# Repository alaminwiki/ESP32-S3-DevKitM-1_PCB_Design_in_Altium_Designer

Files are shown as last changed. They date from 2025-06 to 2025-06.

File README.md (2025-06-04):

Project Highlights:

Designed a 4-layer PCB stack-up to enhance signal integrity and power distribution

Created and customized schematic symbols

Sourced many footprints and 3D model from SnapMagic and Ultra Librarian and also modified some footprint

Explored Differential Pair Routing For high-speed  signals

Used a TVS (Transient Voltage Suppression) diode to protect the microcontroller, USB interface, and power lines from sudden voltage spikes caused by ESD events.

Implemented strategic component placement and return path optimization to mitigate EMI issues, carefully planned layout and return paths to reduce noise, and enhanced board-level EMC performance to meet industry standards 

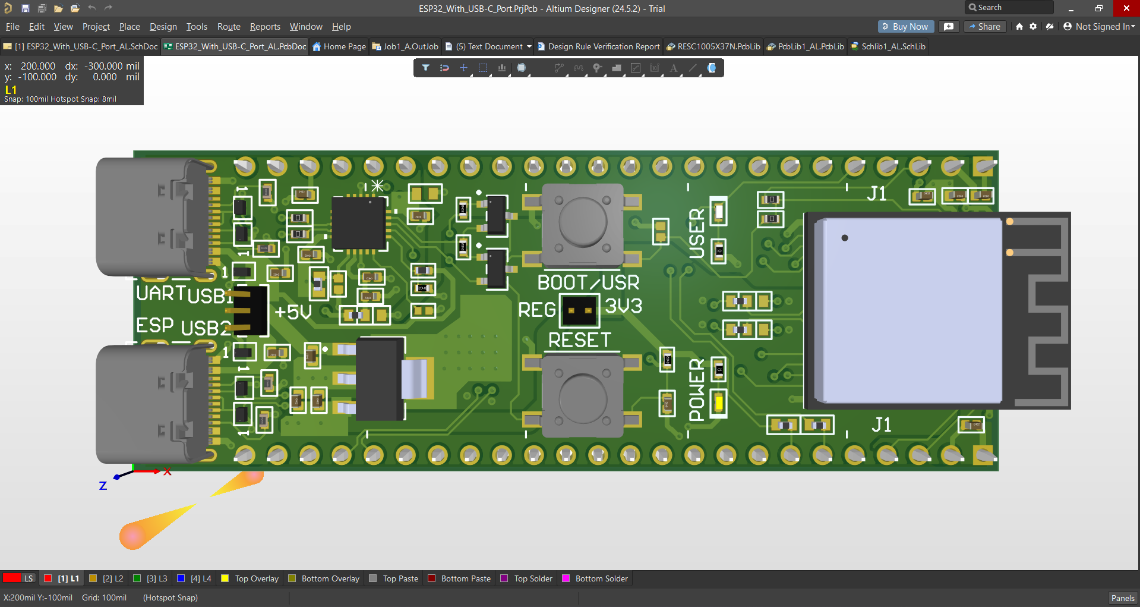
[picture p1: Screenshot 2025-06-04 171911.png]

![image alt]()

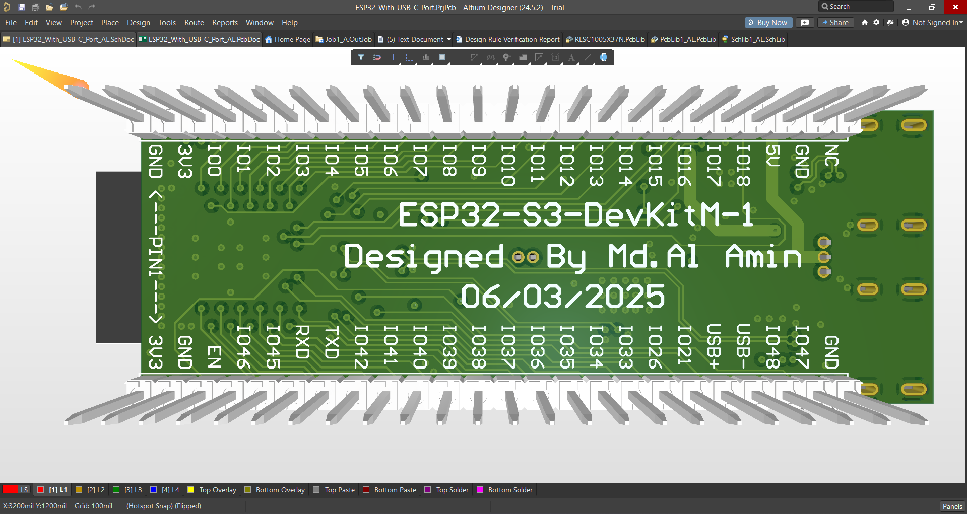
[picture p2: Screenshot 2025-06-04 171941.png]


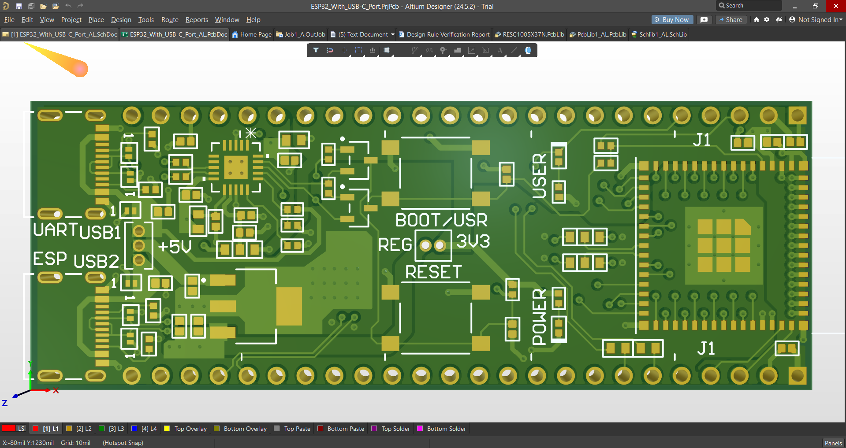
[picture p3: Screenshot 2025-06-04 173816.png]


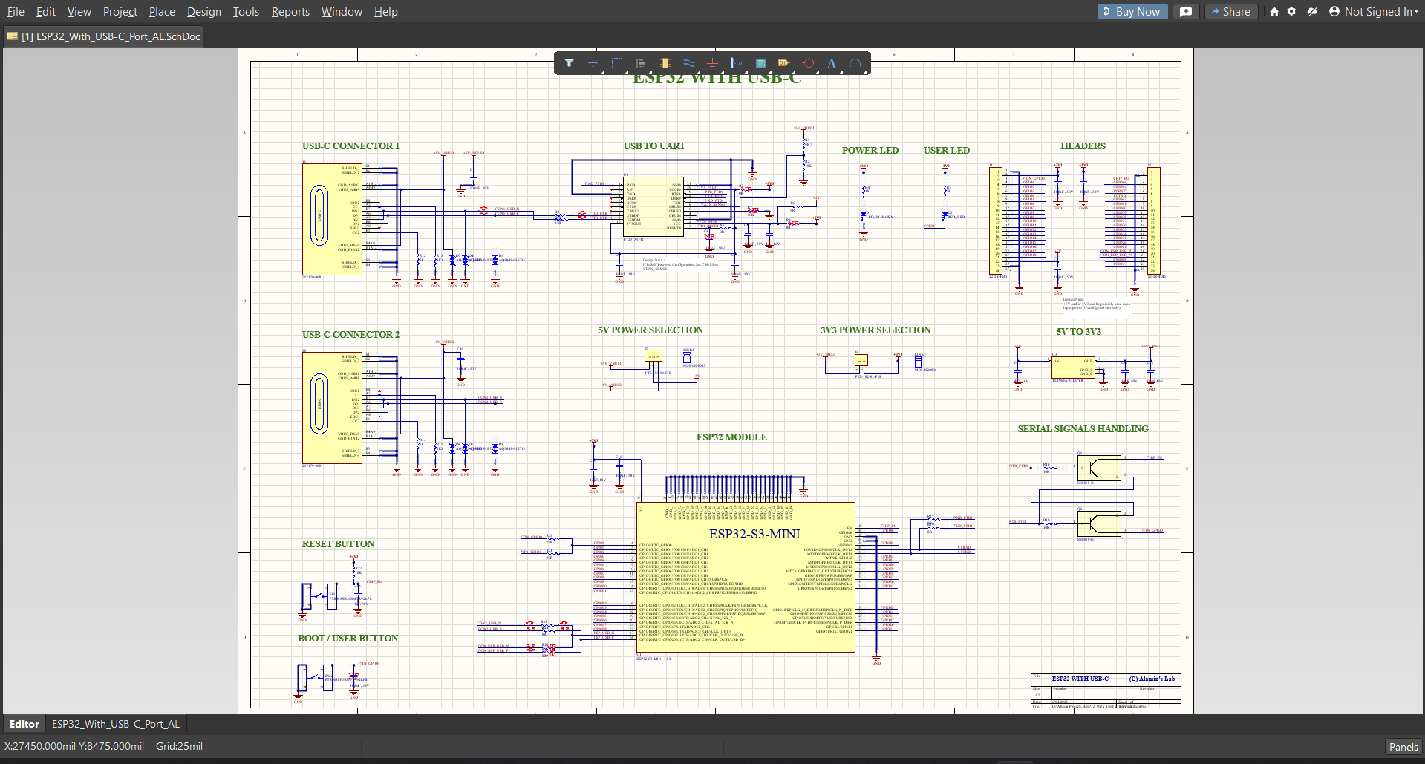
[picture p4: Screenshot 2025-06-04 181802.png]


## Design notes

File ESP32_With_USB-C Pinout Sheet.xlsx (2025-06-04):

1 | GND_1
2 | GND_2
3 | 3V3
4 | GPIO0/RTC_GPIO0
5 | GPIO1/RTC_GPIO1/TOUCH1/ADC1_CH0
6 | GPIO2/RTC_GPIO2/TOUCH2/ADC1_CH1
7 | GPIO3/RTC_GPIO3/TOUCH3/ADC1_CH2
8 | GPIO4/RTC_GPIO4/TOUCH4/ADC1_CH3
9 | GPIO5/RTC_GPIO5/TOUCH5/ADC1_CH4
10 | GPIO6/RTC_GPIO6/TOUCH6/ADC1_CH5
11 | GPIO7/RTC_GPIO7/TOUCH7/ADC1_CH6
12 | GPIO8/RTC_GPIO8/TOUCH8/ADC1_CH7/SUBSPICS1
13 | GPIO9/RTC_GPIO9/TOUCH9/ADC1_CH8/FSPIHD/SUBSPIHD
14 | GPIO10/RTC_GPIO10/TOUCH10/ADC1_CH9/FSPICS0/FSPIIO4/SUBSPICS0
15 | GPIO11/RTC_GPIO11/TOUCH11/ADC2_CH0/FSPID/FSPIIO5/SUBSPID
16 | GPIO12/RTC_GPIO12/TOUCH12/ADC2_CH1/FSPICLK/FSPIIO6/SUBSPICLK
17 | GPIO13/RTC_GPIO13/TOUCH13/ADC2_CH2/FSPIQ/FSPIIO7/SUBSPIQ
18 | GPIO14/RTC_GPIO14/TOUCH14/ADC2_CH3/FSPIWP/FSPIDQS/SUBSPIWP
19 | GPIO15/RTC_GPIO15/U0RTS/ADC2_CH4/XTAL_32K_P
20 | GPIO16/RTC_GPIO16/U0CTS/ADC2_CH5/XTAL_32K_N
21 | GPIO17/RTC_GPIO17/U1TXD/ADC2_CH6
22 | GPIO18/RTC_GPIO18/U1RXD/ADC2_CH7/CLK_OUT3
23 | GPIO19/RTC_GPIO19/U1RTS/ADC2_CH8/CLK_OUT2/USB_D
24 | GPIO20/RTC_GPIO20/U1CTS/ADC2_CH9/CLK_OUT1/USB_D+
25 | GPIO21/RTC_GPIO21
26 | GPIO26/SPICS1
27 | GPIO47/SPICLK_P_DIFF/SUBSPICLK_P_DIFF
28 | GPIO33/SPIIO4/FSPIHD/SUBSPIHD
29 | GPIO34/SPIIO5/FSPICS0/SUBSPICS0
30 | GPIO48/SPICLK_N_DIFF/SUBSPICLK_N_DIFF
31 | GPIO35/SPIIO6/FSPID/SUBSPID
32 | GPIO36/SPIIO7/FSPICLK/SUBSPICLK
33 | GPIO37/SPIDQS/FSPIQ/SUBSPIQ
34 | GPIO38/FSPIWP/SUBSPIWP
35 | MTCK/GPIO39/CLK_OUT3/SUBSPICS1
36 | MTDO/GPIO40/CLK_OUT2
37 | MTDI/GPIO41/CLK_OUT1
38 | MTMS, GPIO42
39 | U0TXD, GPIO43, CLK_OUT1
40 | U0RXD, GPIO44, CLK_OUT2
41 | GPIO45
42 | GND
43 | GND
44 | GPIO46
45 | EN
46 | GND_46
47 | GND_47
48 | GND_48
49 | GND_49
50 | GND_50
51 | GND_51
52 | GND_52
53 | GND_53
54 | GND_54
55 | GND_55
56 | GND_56
57 | GND_57
58 | GND_58
59 | GND_59
60 | GND_60
61 | GND_61
62 | GND_62
63 | GND_63
64 | GND_64
65 | GND_65
66 | GND_66
67 | GND_67
68 | GND_68
69 | GND_69
70 | GND_70
71 | GND_71
72 | GND_72
73 | GND_73

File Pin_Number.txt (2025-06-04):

 RTC_GPIO1,GPIO1,TOUCH1,ADC1_CH0
 RTC_GPIO2,GPIO2,TOUCH2,ADC1_CH1
 RTC_GPIO3,GPIO3,TOUCH3,ADC1_CH2
 RTC_GPIO4,GPIO4,TOUCH4,ADC1_CH3
 RTC_GPIO5,GPIO5,TOUCH5,ADC1_CH4
 RTC_GPIO6,GPIO6,TOUCH6,ADC1_CH5
 RTC_GPIO7,GPIO7,TOUCH7,ADC1_CH6
 RTC_GPIO8,GPIO8,TOUCH8,ADC1_CH7,SUBSPICS1
 RTC_GPIO9,GPIO9,TOUCH9,ADC1_CH8,FSPIHD,SUBSPIHD
 RTC_GPIO10,GPIO10,TOUCH10,ADC1_CH9,FSPICS0,FSPIIO4,SUBSPICS0
 RTC_GPIO11,GPIO11,TOUCH11,ADC2_CH0,FSPID,FSPIIO5,SUBSPID
 RTC_GPIO12,GPIO12,TOUCH12,ADC2_CH1,FSPICLK,FSPIIO6,SUBSPICLK
 RTC_GPIO13,GPIO13,TOUCH13,ADC2_CH2,FSPIQ,FSPIIO7,SUBSPIQ
 RTC_GPIO14,GPIO14,TOUCH14,ADC2_CH3,FSPIWP,FSPIDQS,SUBSPIWP
 RTC_GPIO15,GPIO15,U0RTS,ADC2_CH4,XTAL_32K_P
 RTC_GPIO16,GPIO16,U0CTS,ADC2_CH5,XTAL_32K_N
 RTC_GPIO17,GPIO17,U1TXD,ADC2_CH6
 RTC_GPIO18,GPIO18,U1RXD,ADC2_CH7,CLK_OUT3
 RTC_GPIO19,GPIO19,U1RTS,ADC2_CH8,CLK_OUT2,USB_D
 RTC_GPIO20,GPIO20,U1CTS,ADC2_CH9,CLK_OUT1,USB_D+
 RTC_GPIO21,GPIO21
 SPICS1,GPIO26
 SPICLK_P_DIFF,GPIO47,SUBSPICLK_P_DIFF
 SPIIO4,GPIO33,FSPIHD,SUBSPIHD
 SPIIO5,GPIO34,FSPICS0,SUBSPICS0
 SPICLK_N_DIFF,GPIO48,SUBSPICLK_N_DIFF
 SPIIO6,GPIO35,FSPID,SUBSPID
 SPIIO7,GPIO36,FSPICLK,SUBSPICLK
 SPIDQS,GPIO37,FSPIQ,SUBSPIQ
 GPIO38,FSPIWP,SUBSPIWP
 MTCK,GPIO39,CLK_OUT3,SUBSPICS1
 MTDO,GPIO40,CLK_OUT2
 MTDI,GPIO41,CLK_OUT1

MTMS, GPIO42
U0TXD, GPIO43, CLK_OUT1
U0RXD, GPIO44, CLK_OUT2
GPIO45
GPIO46

EN 45 I
High: on, enables the chip.
Low: off, the chip powers off.
Note: Do not leave the EN pin floating.

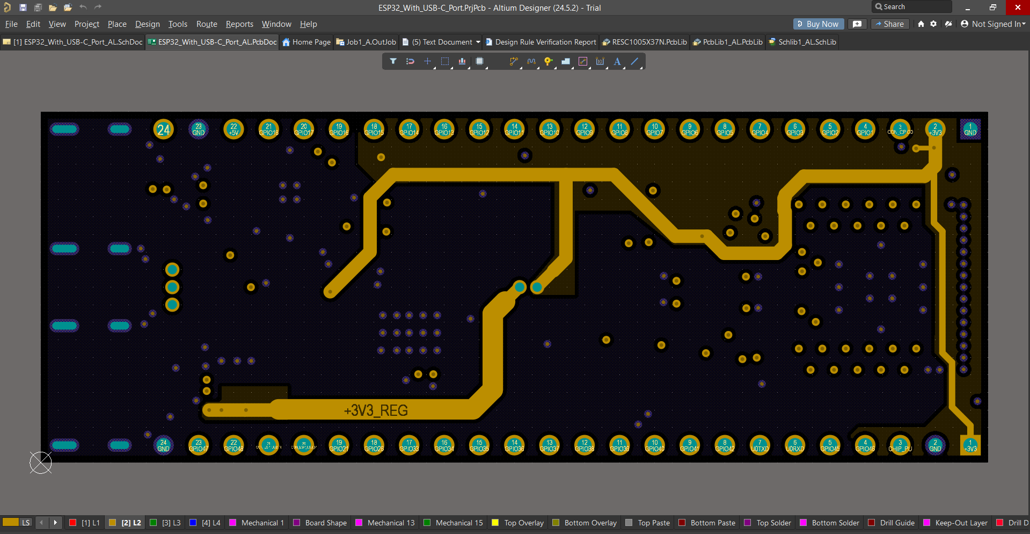
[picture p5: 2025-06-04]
Screenshot 2025-06-04 172349.png

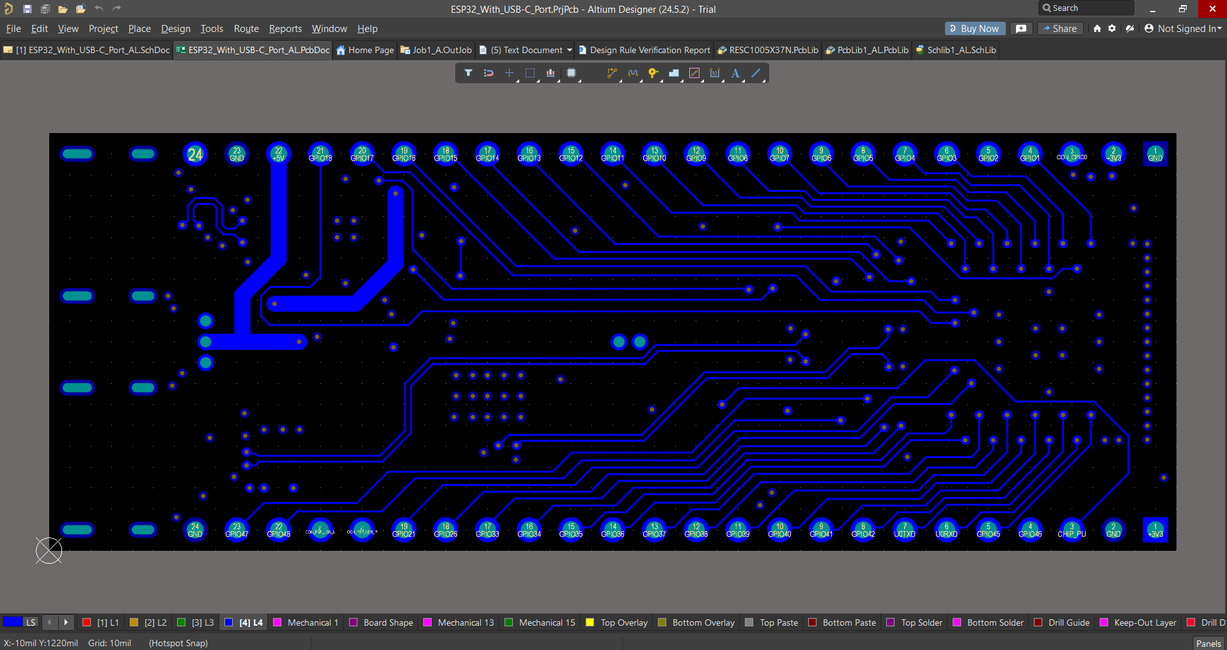
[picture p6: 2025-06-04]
Screenshot 2025-06-04 172502.png

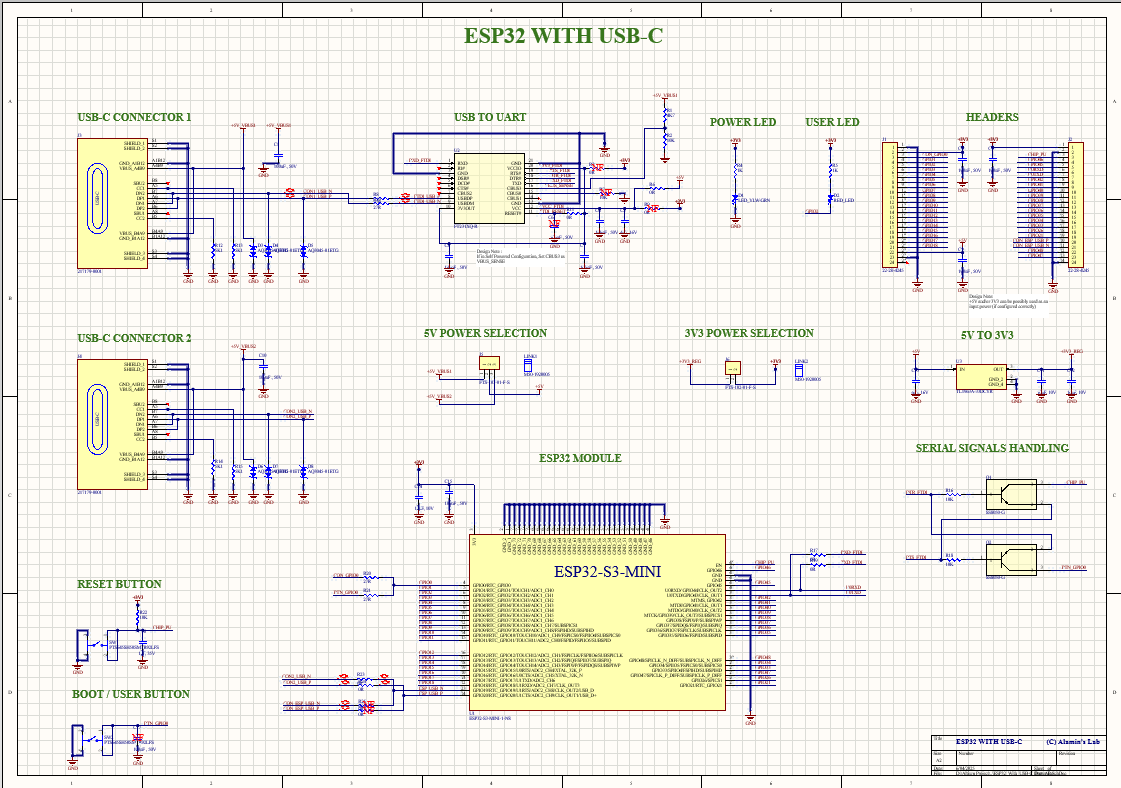
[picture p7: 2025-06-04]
Screenshot 2025-06-04 172717.png

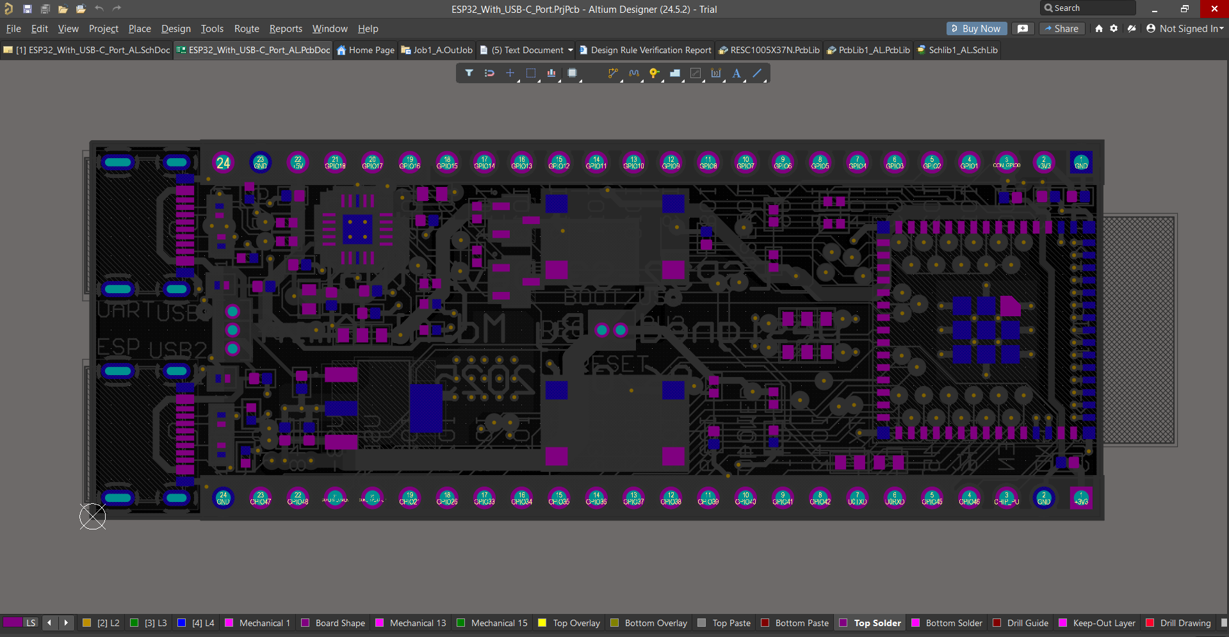
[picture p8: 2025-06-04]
Screenshot 2025-06-04 180557.png

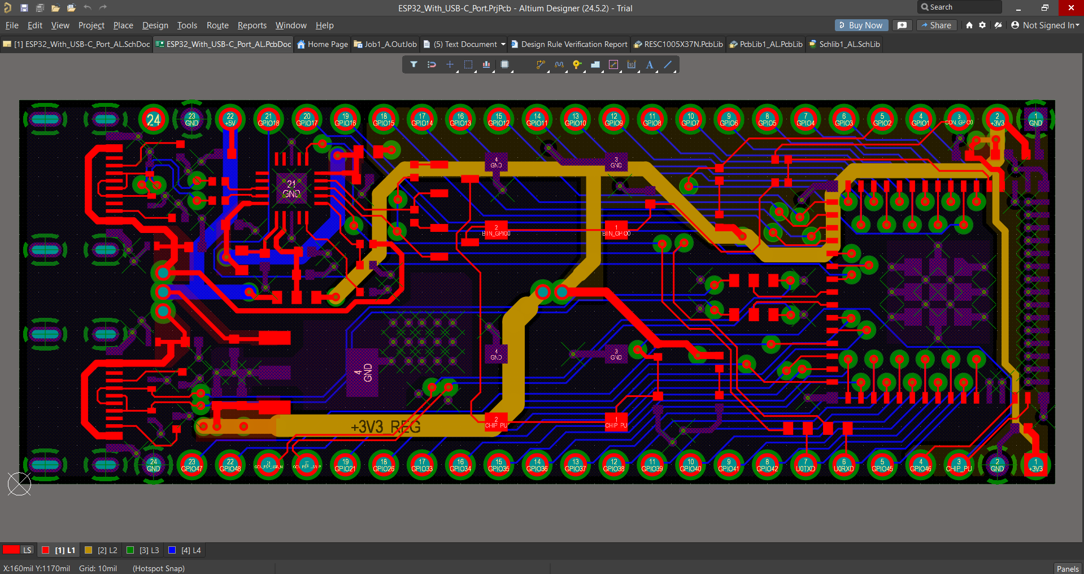
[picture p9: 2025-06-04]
Screenshot 2025-06-04 173255.png

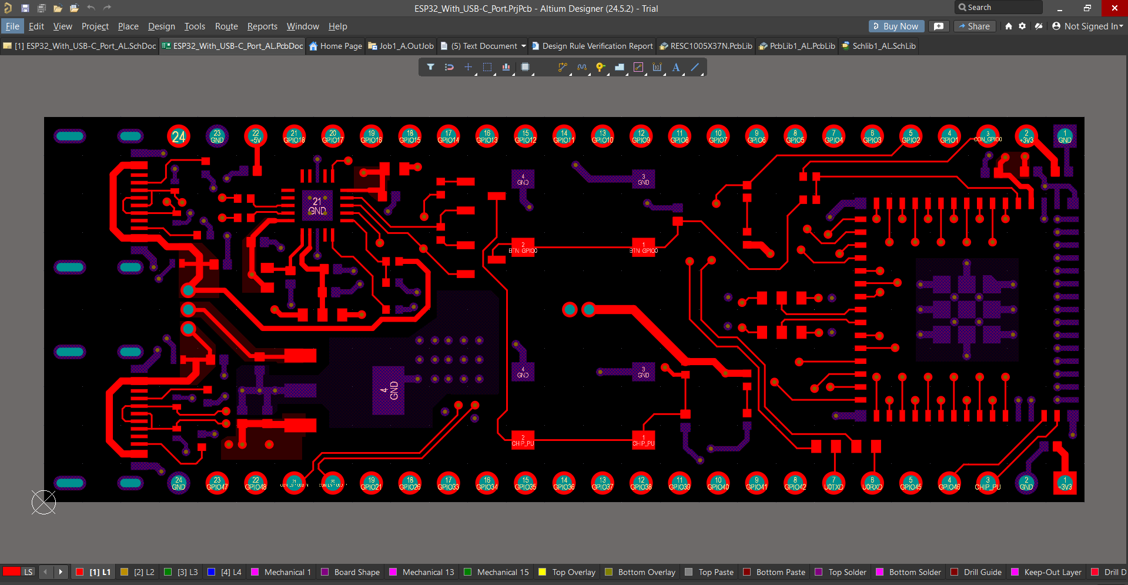
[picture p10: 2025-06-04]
Screenshot 2025-06-04 172311.png

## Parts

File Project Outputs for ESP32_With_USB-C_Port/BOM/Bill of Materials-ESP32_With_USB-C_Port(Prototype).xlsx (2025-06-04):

Comment | Description | Designator | Footprint | LibRef | Quantity | LCSC Part Number | Manufacturer | Manufacturer Part Number | Supplier | Supplier Part Number
100nF , 50V | CAP CER 0.1UF 50V X7R 0402 | C1, C2, C3, C4, C7, C8, C9, C10, C15 | CAPC1005X70N_ALL | CL05B104KB54PNC | 9 | C307331 | Samsung | CL05B104KB54PNC | Digikey | 1276-CL05B104KB54PNCDKR-ND
4u7, 16V | CAP CER 4.7UF 16V X5R 0402 | C5, C13 | CAPC1005X70N_ALL | CL05A475MO5NUNC | 2 | C318563 | Samsung | CL05A475MO5NUNC | Digikey | 1276-6836-1-ND
10uF, 10V | CAP CER 10UF 10V X5R 0402 | C11, C12, C14 | CAPC1005X70N_ALL | CL05A106MP8NUB8 | 3 | C307415 | Samsung | CL05A106MP8NUB8 | Digikey | 1276-6830-6-ND
1uF, 35V | CAP CER 1UF 35V X5R 0402 | C16 | CAPC1005X70N_ALL | CL05A106MP8NUB8 (2) | 1 | C307413 | Samsung | CL05A106MP8NUB8 | Digikey | 1276-6830-1-ND
LED_YLW-GRN | LED YLW-GRN 0402 SMD | D1 | LED_0402_YLW_GR | VLMG1500-GS08 | 1 | C511404 | Vishay | VLMG1500-GS08 | Digikey | VLMG1500-GS08CT-ND
RED_LED | LED RED 0402 SMD | D2 | LED_0402_RED_01- duplicate | VLMS1500-GS08 | 1 | C511370 | Vishay | VLMS1500-GS08 | Digikey | VLMS1500-GS08CT-ND
AQ3045-01ETG | TVS DIODE 5.3VWM 12VC SOD882 | D3, D4, D5, D6, D7, D8 | RTVS_SOD882_LTF-M | AQ3045-01ETG | 6 | C3710326 | Littelfuse | AQ3045-01ETG | Digikey | F9321CT-ND
22-28-4245 | CONN HEADER VERT 24POS 2.54MM | J1, J2 | CONN_SD-42375-001_M295_24_MOL | 22-28-4245 | 2 | C7145888 | Molex | 22-28-4245 | Digikey | 900-0022284245-ND
217179-0001 | CONN RCP USB2.0 TYP C 24P SMD RA | J3, J4 | MOLEX_2171790001 | 217179-0001 | 2 | C3197684 | Molex | 217179-0001 | Digikey | 900-2171790001CT-ND
FTS-103-01-F-S | CONN HEADER VERT 3POS 1.27MM | J5 | CONN_FTS-103-01-x-S_SAI | FTS-103-01-F-S | 1 | C3333578 | Samtec | FTS-103-01-F-S | Digikey | 612-FTS-103-01-F-S-ND
FTS-102-01-F-S | CONN HEADER VERT 2POS 1.27MM | J6 | CONN_FTS-102-01-x-S_SAI | FTS-102-01-F-S | 1 | C6045317 | Samtec | FTS-102-01-F-S | Digikey | SAM15176-ND
M50-1920005 | CONN SHUNT 1.27MM RED | LINK1, LINK2 |  | M50-1920005 | 2 | C6985646 | Harwin | M50-1920005 | Digikey | 952-1727-ND
SS8050-G | TRANS NPN 25V 1.5A SOT-23-3 | Q1, Q2 | TRAN_SS8050-G_CIP | SS8050-G | 2 | C164886 | Comchip | SS8050-G | Digikey | 641-1790-1-ND
4K7 | RES 4.7K OHM 1% 1/16W 0402 | R1 | RESC1005X40N | RC0402FR-074K7L | 1 | C105871 | Yageo | RC0402FR-074K7L | Digikey | 311-4.7KLRCT-ND
10K | RES SMD 10K OHM 1% 1/16W 0402 | R2, R16, R18, R22 | RESC1005X37N_10k | AC0402FR-0710KL | 4 | C144807 | Yageo | AC0402FR-0710KL | Digikey | YAG3436CT-ND
1K | RES 1K OHM 1% 1/16W 0402 | R4, R5 | RESC1005X40N_1k | RC0402FR-071KL | 2 | C106235 | Yageo | RC0402FR-071KL | Digikey | 311-1.00KLRCT-ND
0R | RES 0 OHM JUMPER 1/16W 0402 | R6, R11, R17, R19, R23, R24 | RESC1005X40_0 | RC0402JR-070RL | 6 | C60485 | Yageo | RC0402JR-070RL | Digikey | 311-0.0JRCT-ND
27R | RES 27 OHM 1% 1/16W 0402 | R8, R10, R20, R21 | RESC1005X40N_27 | RC0402FR-0727RL | 4 | C138021 | Yageo | RC0402FR-0727RL | Digikey | YAG3086CT-ND
5K1 | RES SMD 5.1K OHM 1% 1/16W 0402 | R12, R13, R14, R15 | RESC1005X37N_5.1 | AC0402FR-075K1L | 4 | C144745 | Yageo | AC0402FR-075K1L | Digikey | YAG3503CT-ND
PTS645SH50SMTR92LFS | SWITCH TACTILE SPST-NO 0.05A 12V | SW1, SW2 | PTS645S_SMTR92_CNK | PTS645SH50SMTR92LFS | 2 | C221869 | ITT C&K | PTS645SH50SMTR92LFS | Digikey | CKN9085CT-ND
ESP32-S3-MINI-1-N8 | SMD module, ESP32-S3FN8, 8 MB SPI flash, PCB antenna | U1 | XCVR_ESP32-S3-MINI-1-N8 | ESP32-S3-MINI-1-N8 | 1 | C2913206 | Espressif Systems | ESP32-S3-MINI-1-N8 | Digikey | 5407-ESP32-S3-MINI-1-N8CT-ND
FT231XQ-R | IC USB SERIAL FULL UART 20QFN | U2 | QFN20_FT231XQ_FTD-M | FT231XQ-R | 1 | C132159 | FTDI | FT231XQ-R | Digikey | 768-1128-1-ND
TL1963A-33DCYR | IC REG LIN 3.3V 1.5A SOT-223-4 | U3 | VREG_TL1963A-33DCYR | TL1963A-33DCYR | 1 | C181262 | Texas Instruments | TL1963A-33DCYR | Digikey | 296-24897-1-ND

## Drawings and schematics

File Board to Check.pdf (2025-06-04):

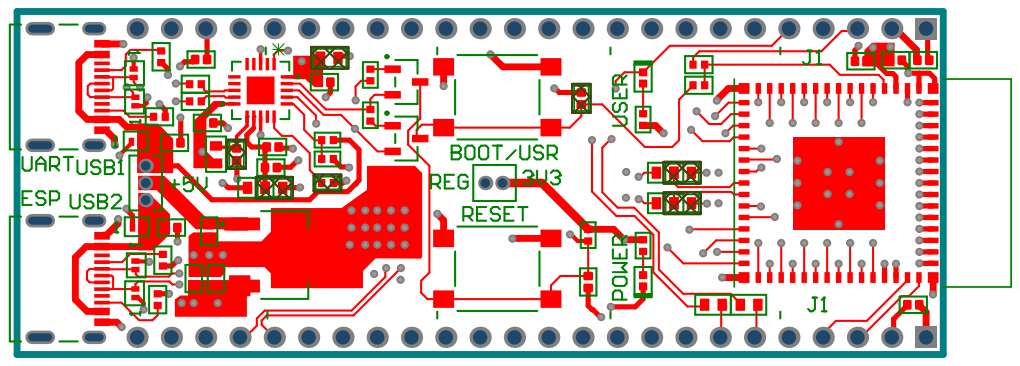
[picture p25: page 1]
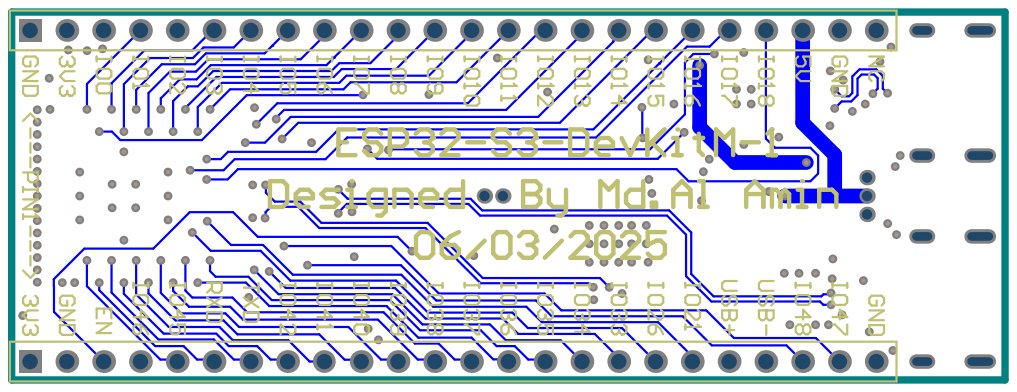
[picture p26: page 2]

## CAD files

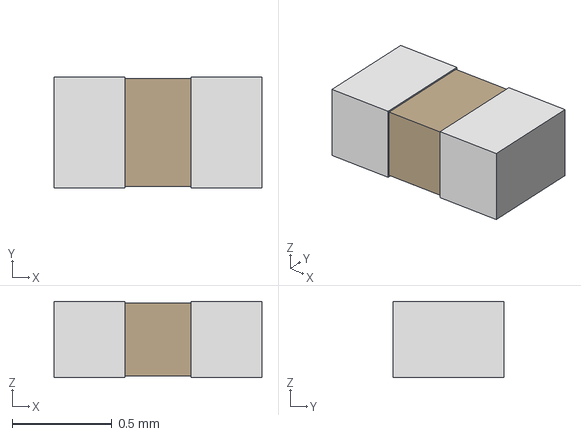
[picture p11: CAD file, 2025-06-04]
Footprint & 3D Model/10K Resistor Footprint Ultra/AC0402FR_0710KL/AltiumDesigner/RES_AC0402FR_YAG.step
1.04 x 0.558 x 0.381 mm

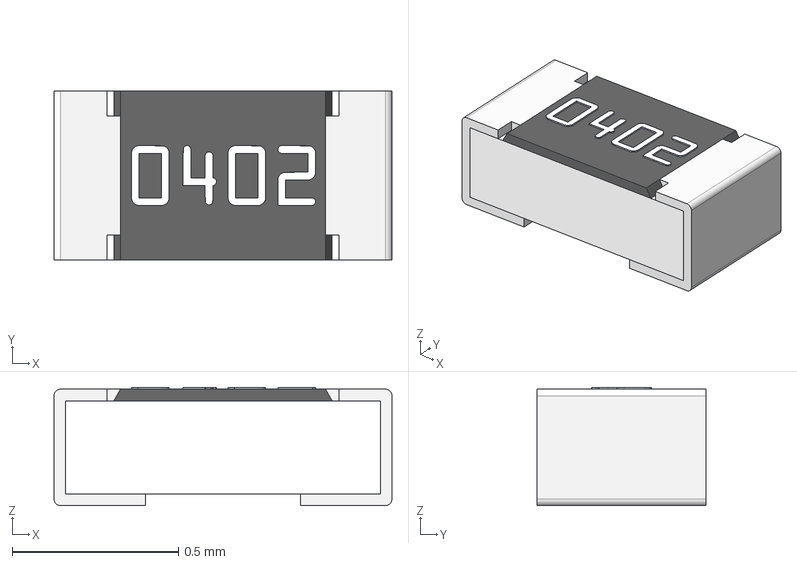
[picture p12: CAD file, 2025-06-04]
Footprint & 3D Model/10k Resistor Footprint Snap Magic/Resistor_0402_Text.step
1.02 x 0.508 x 0.355 mm
Pin1Body
Pin2Body
CeramicBody
CoatingBody
Text1Body
Text2Body
Text3Body
Text4Body

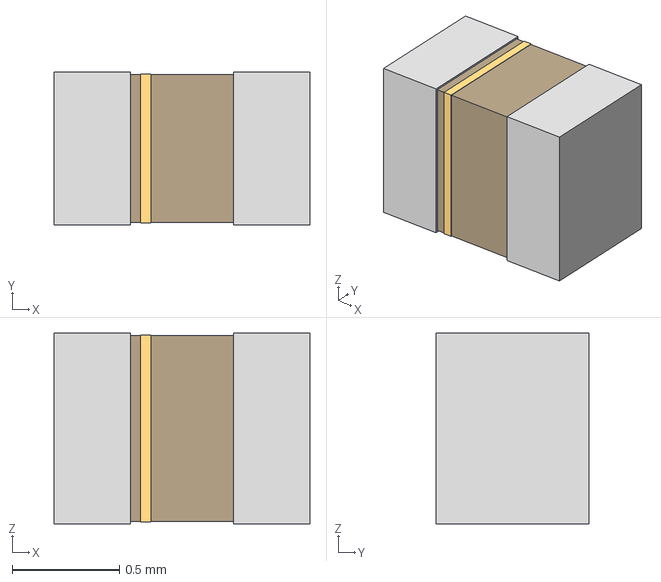
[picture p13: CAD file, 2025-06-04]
Footprint & 3D Model/10uF 10V Capacitor Footprint ultra/CL05A106MP8NUB8/AltiumDesigner/CAP_CL05A106MP8NUB8_SAM.step
1.19 x 0.712 x 0.889 mm

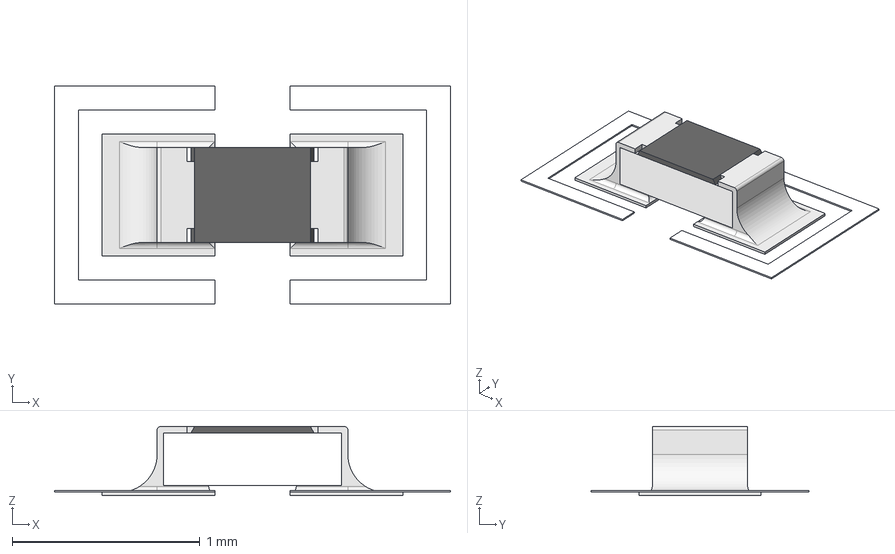
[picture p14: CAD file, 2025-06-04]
Footprint & 3D Model/1K Resistor Snap/resistor-0402-1.snapshot.5/Resistor_0402_Solder_Silk.step
2.11 x 1.16 x 0.367 mm
Pin1Body
Pin2Body
CeramicBody
CoatingBody
Silk1Body
Silk2Body

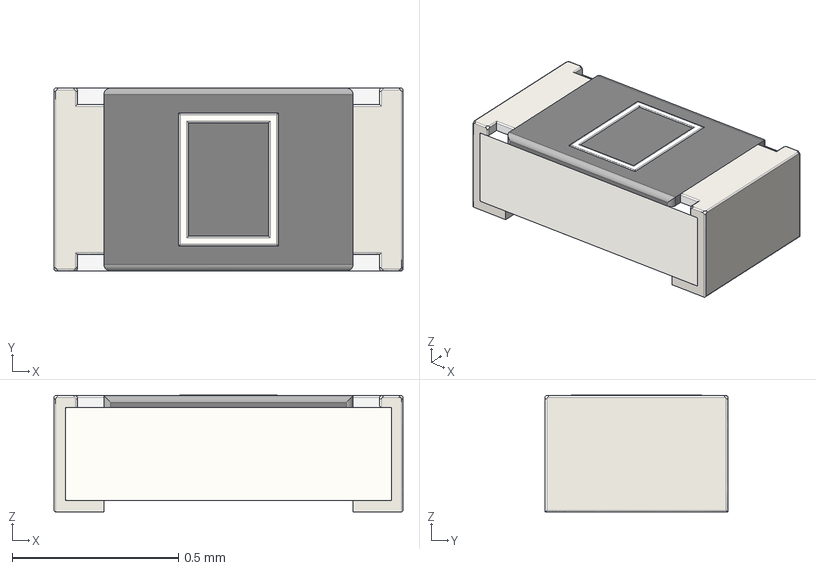
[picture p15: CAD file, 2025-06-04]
Footprint & 3D Model/27_Ohm_Resistor Footprint/smd-resistor-0402-1005-0ohm-1.snapshot.3/RESC1005X04L - 0ohm.step
1.05 x 0.55 x 0.352 mm
Mid Body
Mark

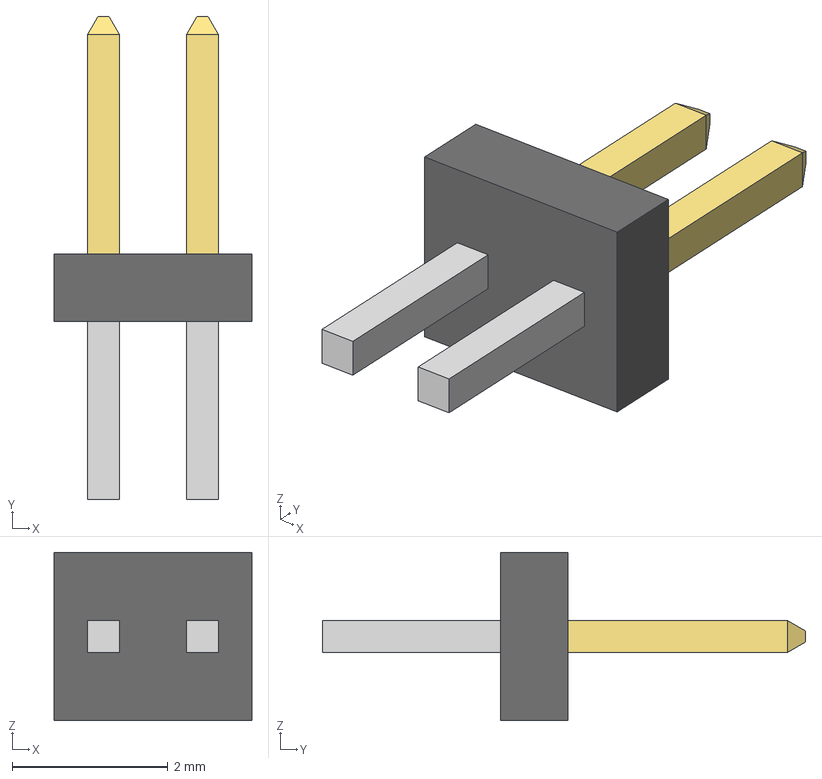
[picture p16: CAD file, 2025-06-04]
Footprint & 3D Model/2_Pin_Male_Header_Samtec/FTS-102-01-F-S/FTS-102-01-F-S.stp
2.54 x 6.20 x 2.16 mm
FTS-102-01-F-S_body
FTS-102-01-F-S_pins1
FTS-102-01-F-S_pins2

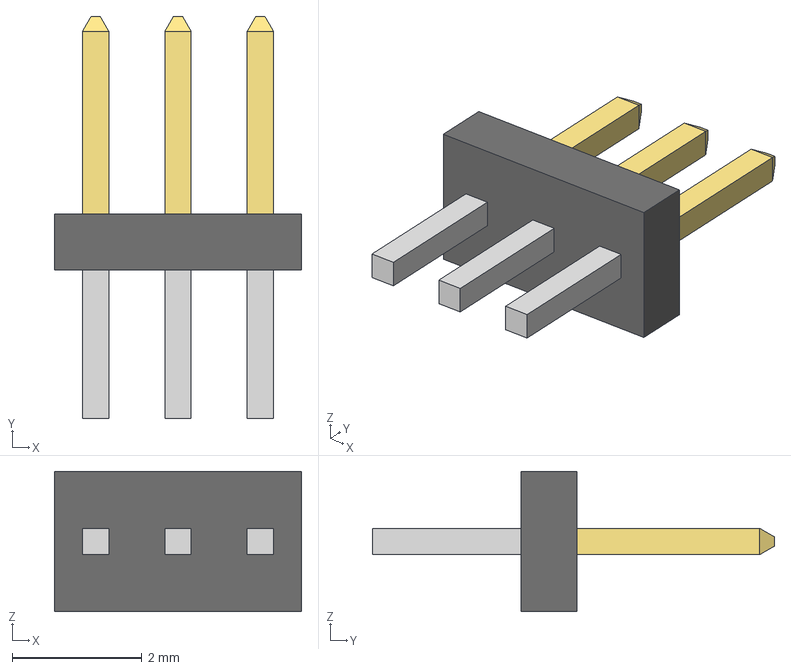
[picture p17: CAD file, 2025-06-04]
Footprint & 3D Model/3_Pin_Header_FOOTPRINT_SAMTEC/FTS-103-01-F-S/FTS-103-01-F-S.stp
3.81 x 6.20 x 2.16 mm
FTS-103-01-F-S_body
FTS-103-01-F-S_pins1
FTS-103-01-F-S_pins2

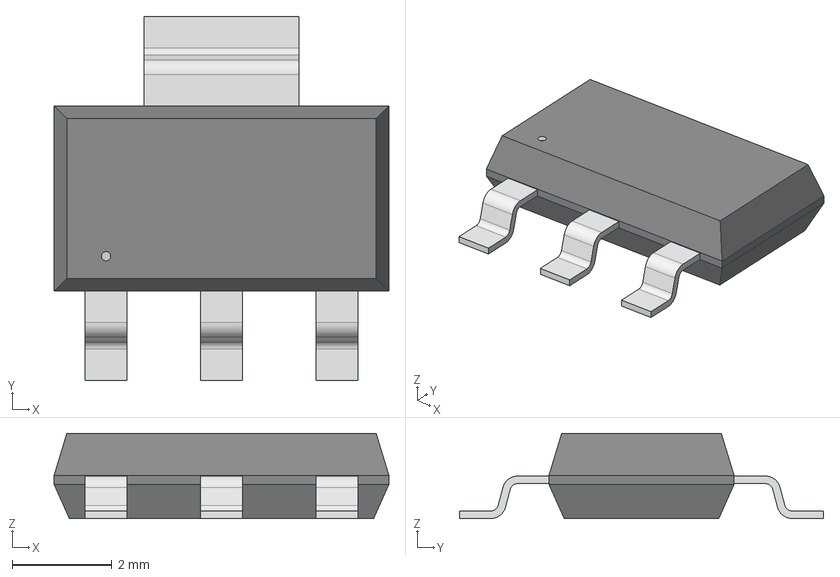
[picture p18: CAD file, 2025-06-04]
Footprint & 3D Model/3V3_Voltage_Regulator/TL1963A_33DCYR/AltiumDesigner/DCY4_TEX.step
6.71 x 7.29 x 1.70 mm

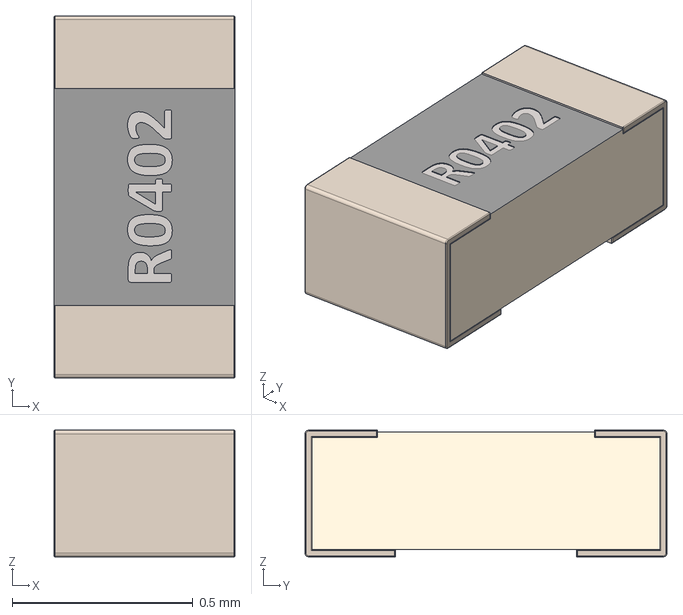
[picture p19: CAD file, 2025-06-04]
Footprint & 3D Model/5.1K Resistor Footprint/R0402.step
0.5 x 1.00 x 0.35 mm

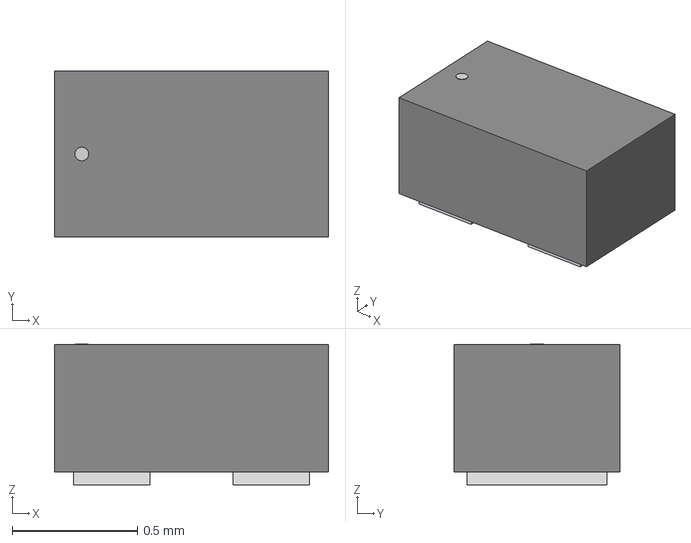
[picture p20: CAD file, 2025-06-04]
Footprint & 3D Model/AQ3045 Series_Low Capacitance ESD Protection Footprint ULTRA/AQ3045_01ETG/AltiumDesigner/RTVS_SOD882_LTF.step
1.09 x 0.66 x 0.561 mm

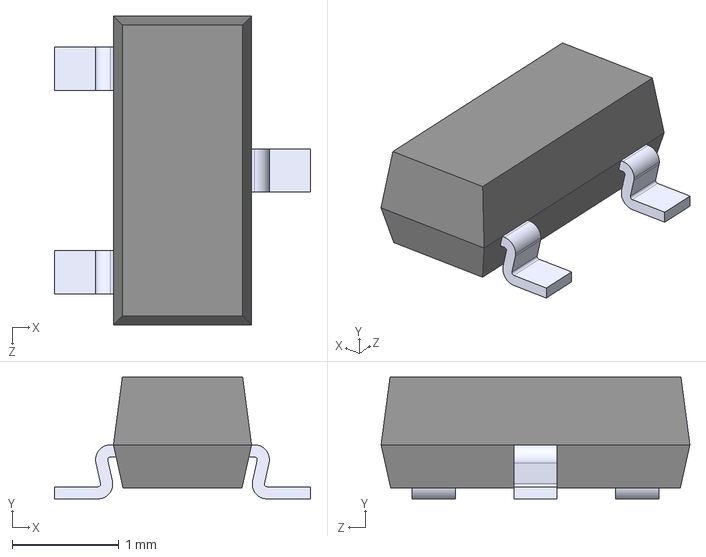
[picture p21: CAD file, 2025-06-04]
Footprint & 3D Model/BJT/SS8050_G/SS8050-G.STEP
2.40 x 1.14 x 2.90 mm

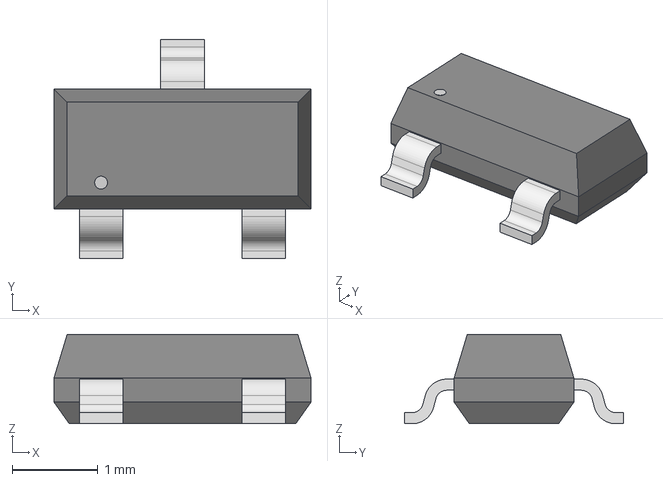
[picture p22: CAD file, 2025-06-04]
Footprint & 3D Model/BJT_ULTRA/AltiumDesigner/TRAN_SS8050-G_CIP.step
3.00 x 2.55 x 1.04 mm

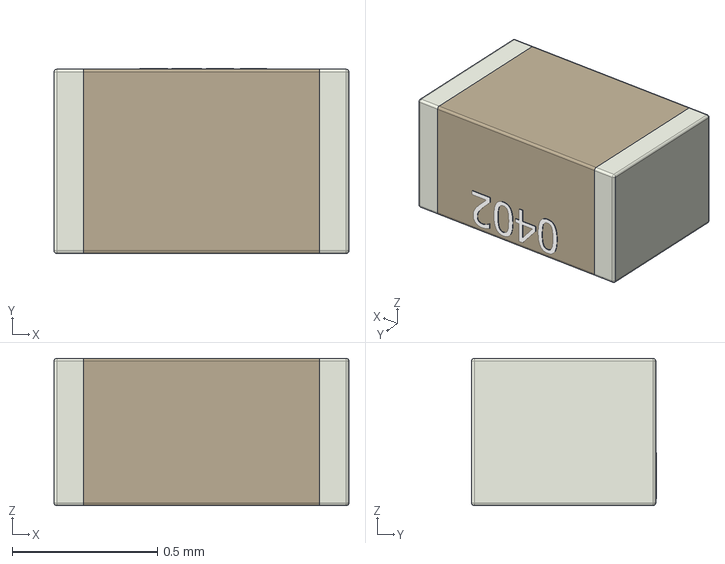
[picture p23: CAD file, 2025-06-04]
Footprint & 3D Model/Capacitor_Footprint_0402/0402_smt_capacitor-1.snapshot.1/0402_CAP.stp
1.02 x 0.638 x 0.508 mm
Capsule
Encapsulation x 2

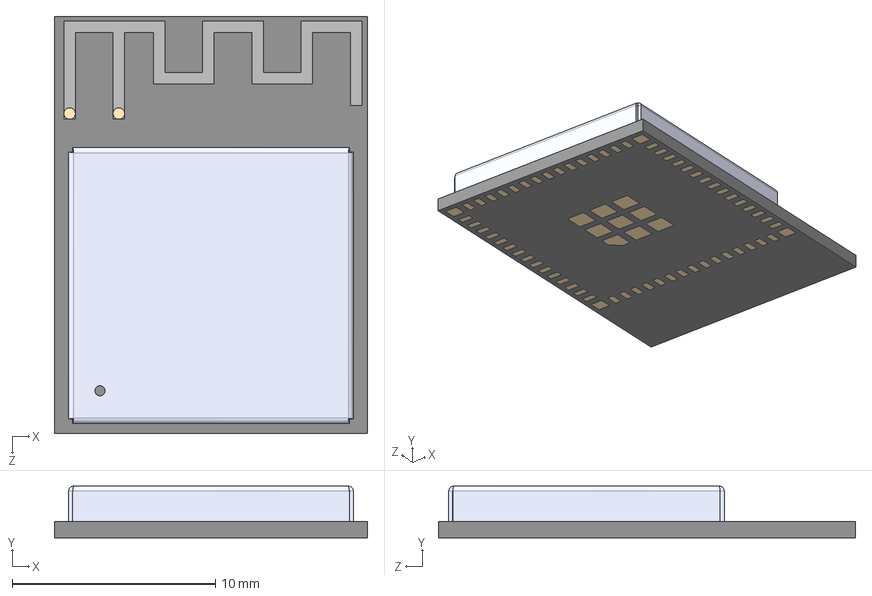
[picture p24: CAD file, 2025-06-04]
Footprint & 3D Model/ESP32-S3-MINI-1-N8 FOOTPRINT/ESP32_S3_MINI_1_N8 (1)/ESP32-S3-MINI-1-N8.STEP
15.4 x 2.55 x 20.5 mm

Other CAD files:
Footprint & 3D Model/10K Resistor Footprint Ultra/AC0402FR_0710KL/RES_AC0402FR_YAG.step
Footprint & 3D Model/10uF 10V Capacitor Footprint ultra/CL05A106MP8NUB8/CAP_CL05A106MP8NUB8_SAM.step
Footprint & 3D Model/BJT_ULTRA/TRAN_SS8050-G_CIP.step
Footprint & 3D Model/0 ohm Resistor Footprint/RC0402JR_070RL (1)/RC0402JR-070RL.step
Footprint & 3D Model/10k Resistor Footprint Snap Magic/AC0402FR_0710KL (1)/RESC1005X37N.step
Footprint & 3D Model/1K Resistor Snap/RC0402FR_071KL (1)/RC0402FR-071KL.step
Footprint & 3D Model/1K Resistor Snap/resistor-0402-1.snapshot.5/Resistor_0402.step
Footprint & 3D Model/1K Resistor Snap/resistor-0402-1.snapshot.5/Resistor_0402_Ohm.step
Footprint & 3D Model/1K Resistor Snap/resistor-0402-1.snapshot.5/Resistor_0402_Solder.step
Footprint & 3D Model/24_Male_Conn_Header/22284245/022284245.stp
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

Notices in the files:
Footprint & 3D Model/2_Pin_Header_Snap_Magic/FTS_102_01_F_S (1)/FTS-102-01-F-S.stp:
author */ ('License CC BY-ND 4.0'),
